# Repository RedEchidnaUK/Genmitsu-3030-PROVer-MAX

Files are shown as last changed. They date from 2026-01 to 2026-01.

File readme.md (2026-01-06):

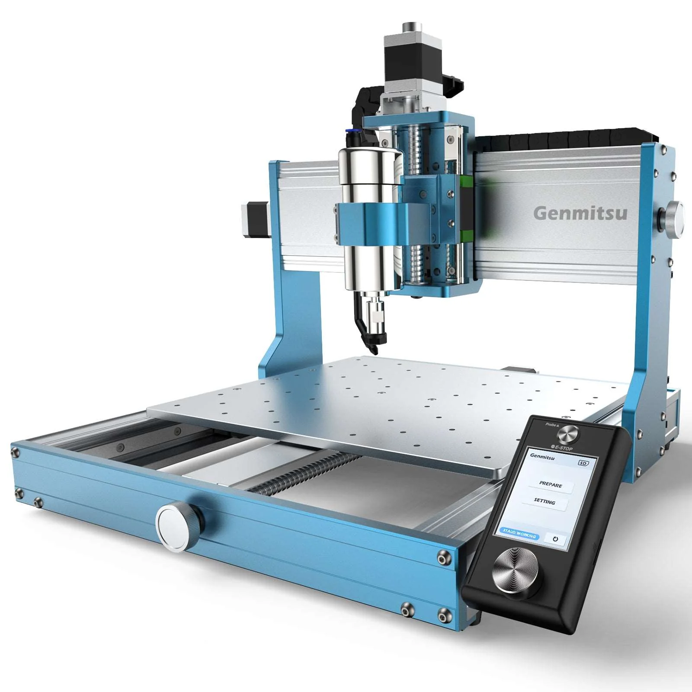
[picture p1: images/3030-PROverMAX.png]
Photo of Genmitsu 3030 PROVer MAX


# Overview
This repository is to document information and modifications on the [Genmitsu 3030 PROVer MAX](https://www.sainsmart.com/products/3030-prover-max) Desktop CNC Router.

Each folder contains information and files about a specific topic.

# Contents
1. [Enclosure](./enclosure/readme.md)
2. [Probes](./probes/readme.md)
3. [E-Stops](./estops/readme.md)
4. [Micro PCB](./microPCB/readme.md) for custom probes and E-Stops

## Notes
* All of this information is provided as is and is not intended as a fully detailed guide. 
* No warranty is provided and you use the information at your own risk. 
* If you break your CNC or your cat/dog goes paws up you can not say you were not warned.

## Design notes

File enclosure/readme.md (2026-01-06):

# Enclosure
This section contains information on building an enclosure for the CNC.

It is designed for the standard range of travel motions and with the standard stepper motors in place. If you modify any of these, you may have to make changes to the size of the enclosure. Although not tested, it has been designed to allow for the use of a 1.5Kw 65mm spindle.

The offline controller should be placed outside the enclosure and may be attached with M4 T-Nuts. The cables should be just long enough, but if they are not extensions may be found on AliExpress (search for JST PH and JST PHB extensions)

It is recommended to read through all of this information prior to commencing any work.
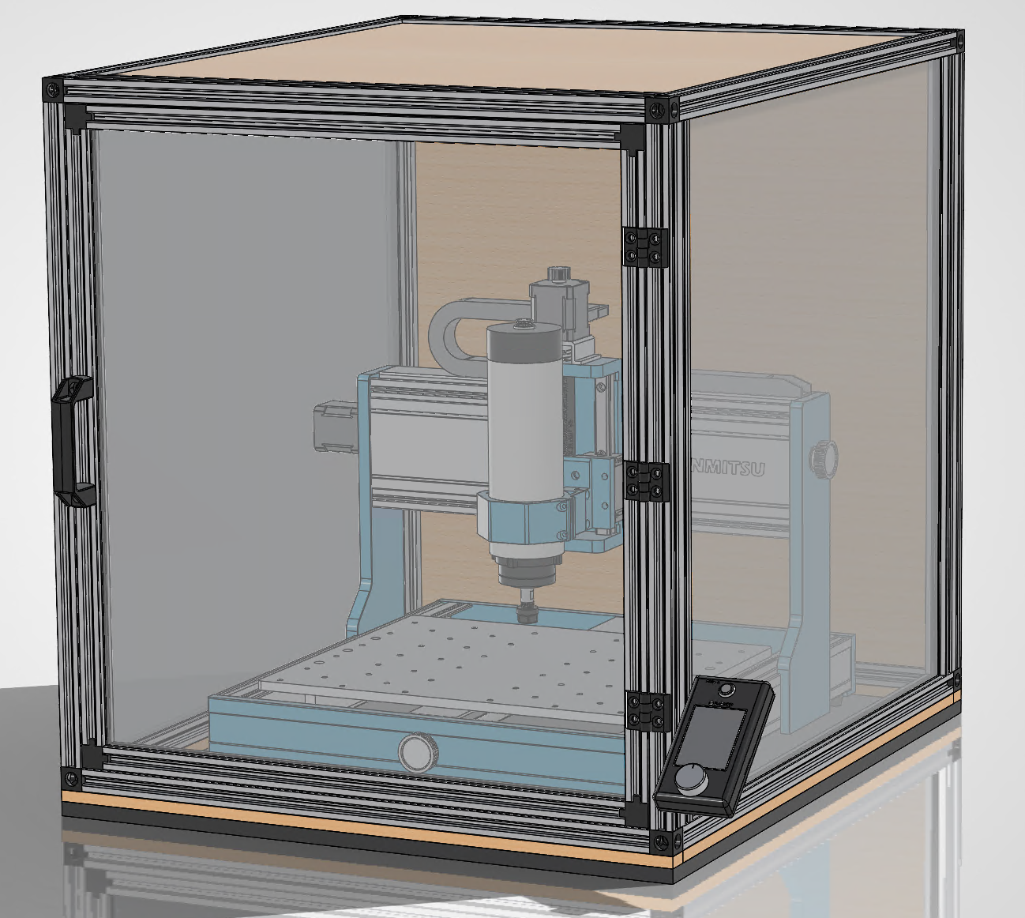
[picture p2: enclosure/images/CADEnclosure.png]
Enclosure CAD model

<sup>1</sup> Genmitsu CAD model shown is from [Printables](https://www.printables.com/model/1285038-genmitsu-3030-prover-max)

## Bill of Materials (BOM)

### Purchased Parts
| Item | Quantity | Supplier (UK) | Notes |
| - | - | - | - |
| **2020** Aluminium Extrusion (**478mm**) | 2 | [Ooznest](https://ooznest.co.uk/) | Tapped both ends (Door top/bottom)|
| **2020** Aluminium Extrusion (**518mm**) | 2 | [Ooznest](https://ooznest.co.uk/) | Tapped both ends  (Door sides) |
| **2020** Aluminium Extrusion (**520mm**) | 2 | [Ooznest](https://ooznest.co.uk/) | Tapped both ends (Front/Rear base) |
| **2020** Aluminium Extrusion (**620mm**) | 4 | [Ooznest](https://ooznest.co.uk/) | Tapped both ends (Sides) |
| **2040** Aluminium Extrusion (**520mm**) | 2 | [Ooznest](https://ooznest.co.uk/) | Tapped both ends (Front/Rear top) |
| **2040** Aluminium Extrusion (**560mm**) | 4 | [Ooznest](https://ooznest.co.uk/) | Tapped both ends (Front/Rear sides) |
| 20 Series T/V-Slot Panel Sealing Strip | 12m | [Ooznest](https://ooznest.co.uk/) | Lubrication was required even with 3mm panel. Strips are a hard plastic and not rubber. Alternatives may be better |
| 2020 Door Handle | 1 | [Ooznest](https://ooznest.co.uk/) | |
| 2020 Hinge | 3 | [Ooznest](https://ooznest.co.uk/) | |
| M4 T-Nut | 16 | [Ooznest](https://ooznest.co.uk/) | |
| M5 T-Nut | 14 | [Ooznest](https://ooznest.co.uk/) | |
| M4x12 CSK Screw | 8 | [Ooznest](https://ooznest.co.uk/) | Length depends on the stripwood thickness|
| M5x8 Low Profile Screw | 12 | [Ooznest](https://ooznest.co.uk/) | Door Hinges |
| M5x14 CSK Screw | 8 | [Ooznest](https://ooznest.co.uk/) | Only required if using the 3D printed corners. |
| 2020 Corner Cube | 12/8 | [Amazon](https://www.amazon.co.uk/dp/B08Z3GRQCW/?coliid=I1LXS3MRZ1L2MV&colid=A492FOWYBVRB&th=1) | UK use 5mm screws, other countries use 6mm. This kit contained both. Only 8 required if using the 3D printed corners. |
| Polycarbonate Sheet (**530mm x 570mm**) | 2 | [SimplyPlastics](https://www.simplyplastics.com/catalog/sheet/polycarbonate-sheet/clear-polycarbonate-sheet/c-24/c-90/p-256) | Sides |
| Polycarbonate Sheet (**488mm x 528mm**) | 1 | [SimplyPlastics](https://www.simplyplastics.com/catalog/sheet/polycarbonate-sheet/clear-polycarbonate-sheet/c-24/c-90/p-256) | Door |
| Plywood/MDF Top (**530mm x 590mm**)| 1 | Local builders merchant, Wickes, B&Q etc. | See [Assembly Notes](#wood-panels) |
| Plywood/MDF Rear (**530mm x 570mm**)| 1 | Local builders merchant, Wickes, B&Q etc. | See [Assembly Notes](#wood-panels) |
| 20mm wide stripwood Front/Rear **560mm** | 2 | Local builders merchant, Wickes, B&Q etc. | Can use offcuts from the wood panels |
| 20mm wide stripwood Side **620mm** | 2 | Local builders merchant, Wickes, B&Q etc. | Can use offcuts from the side panels |
| Anti-Vibration Matting) | 1 | [Screwfix](https://www.screwfix.com/p/essentials-shock-absorbing-floor-mat-black-620mm-x-620mm-x-12mm/967KN) | Slightly undersized in the length, but the width offcuts may be attached with polyurethane adhesive.|
| 20mm x 4mm x 2mm thick N42 Neodymium Magnet - 1.9kg Pull | 8 | [First4Magnets](https://www.first4magnets.com/product/20-x-4-x-2mm-thick-n42-neodymium-magnet-19kg-pull-19305?variant=1151) | |
| 6mm x 6mm Flexible LED Strip | 3m | [AliExpress](https://www.aliexpress.com/item/1005007424507477.html) | |

### Optional 3D Printed Parts
| Item | Quantity | Link | Notes |
| - | - | - | - |
| 2020 2-Way Corner Cube | 4 | [3MF file](./3DPrintFiles/2020CornerCube2Way.3mf) | A normal cube may be used but you will have to notch the panel corners. |
| Magnet Holder | 4 | [3MF file](./3DPrintFiles/MagnetHolder.3mf) | The magnets could be directly glued in place. |

# Assembly Notes

## Wood Panels
A 'half sheet' (606 x 1220mm/2' x 4') cut carefully will be enough for both the rear and top panel as well as the base strips.

Depending on the thickness of the wood purchased  you may have to rabbet the edge to fit in the Aluminium extrusion or Panel Sealing Strip.

The corners on the rear panel will also have to be removed to fit around the corner cube

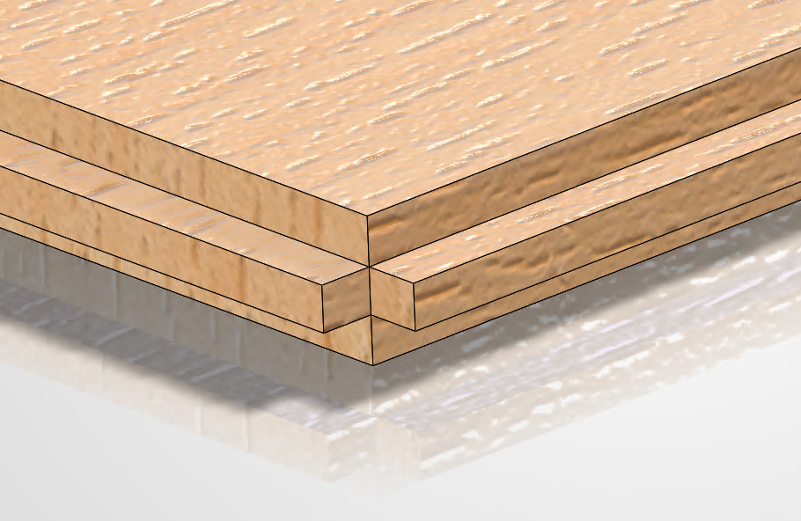
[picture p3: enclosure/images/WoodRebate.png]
Wood Rabbet


## Base Strips
Strips of wood are fitted around the base and are held in place by M4 CSK screws and T-Nuts. These are designed to allow notches to be easily cut for any wires coming in/out of the enclosure.

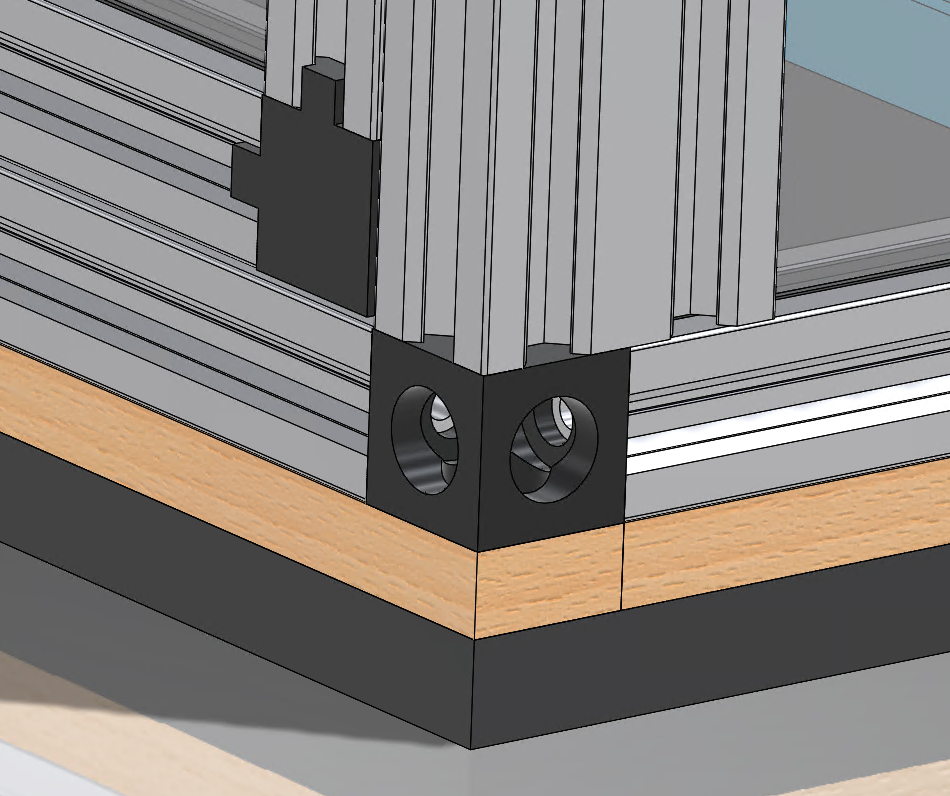
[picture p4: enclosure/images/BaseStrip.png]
Wood Base Strip


## Door
### Door Panel Corners
If you are not using the 3D printed corner cubes you will need to remove the corners of the door panel in the same way as the wood panels to fit around the corner cubes.

The [3D printed corner cubes](./3DPrintFiles/2020CornerCube2Way.3mf) have notches in them to avoid this modification

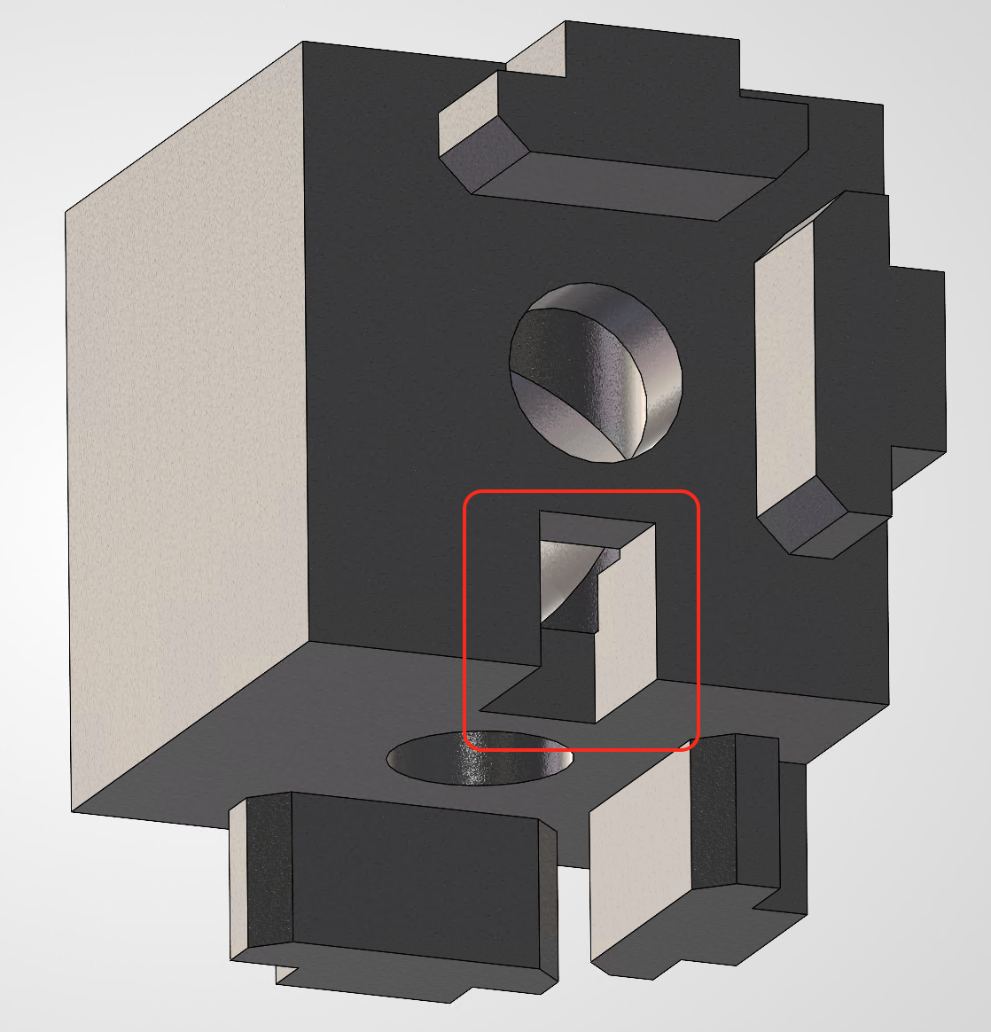
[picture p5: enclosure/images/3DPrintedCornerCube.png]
3D Printed Corner Cube


### Door Magnets
Magnets may be used to create a surprisingly good invisible door catch. Make sure to put the magnets in the correct orientation and align them opposite each other so they are attracted to each other when the door is closed. 

> [!TIP]
> Each [3D printed holder](./3DPrintFiles/MagnetHolder.3mf) is designed to have two magnets fitted, but the number may be adjusted to change the strength of the catch.

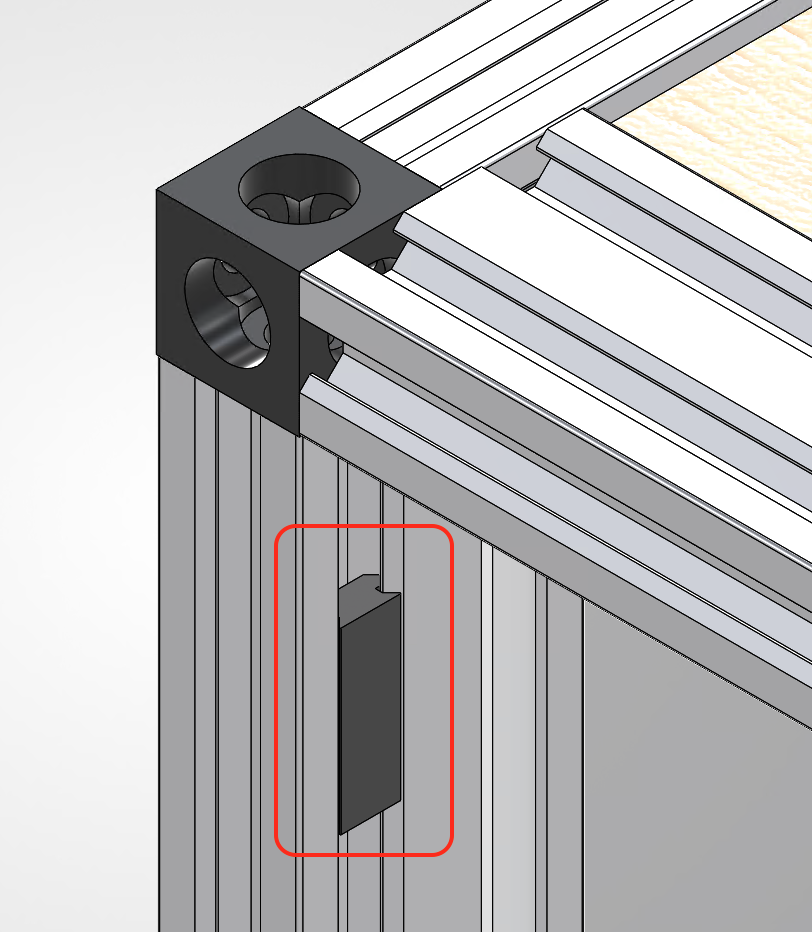
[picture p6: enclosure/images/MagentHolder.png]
Door Magnets


If you are concerned with the door being opened during operation and someone being injured, fit a lockable catch or a magnetic switch to trigger the [E-Stop](../estops/readme.md).

## LED Lighting
6mm x 6mm narrow flexible LED strips fit perfectly in the 6mm wide and deep channels of the 2040 extrusion at the front and rear of the enclosure.
Simply push fit them in one side, over the top and down the other side. 

Modify the extrusions as required to allow the wires to exit the enclosure.

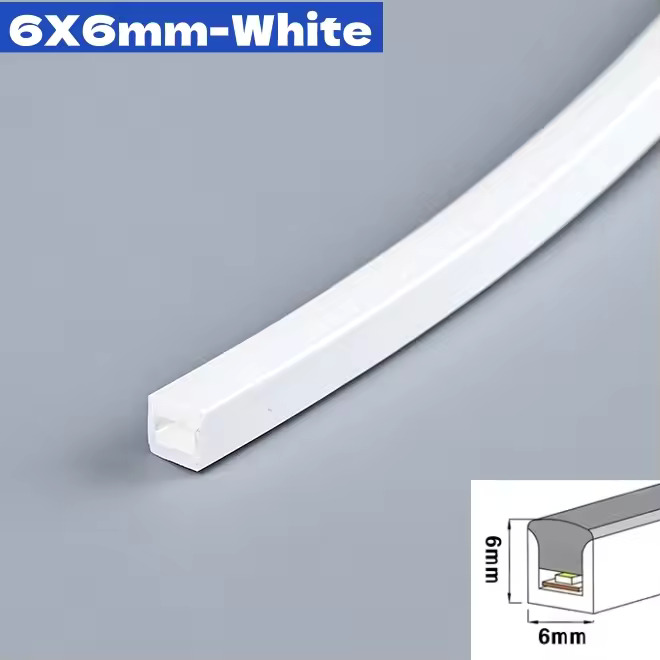
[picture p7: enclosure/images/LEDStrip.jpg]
6mm x 6mm Flexible LED Strip


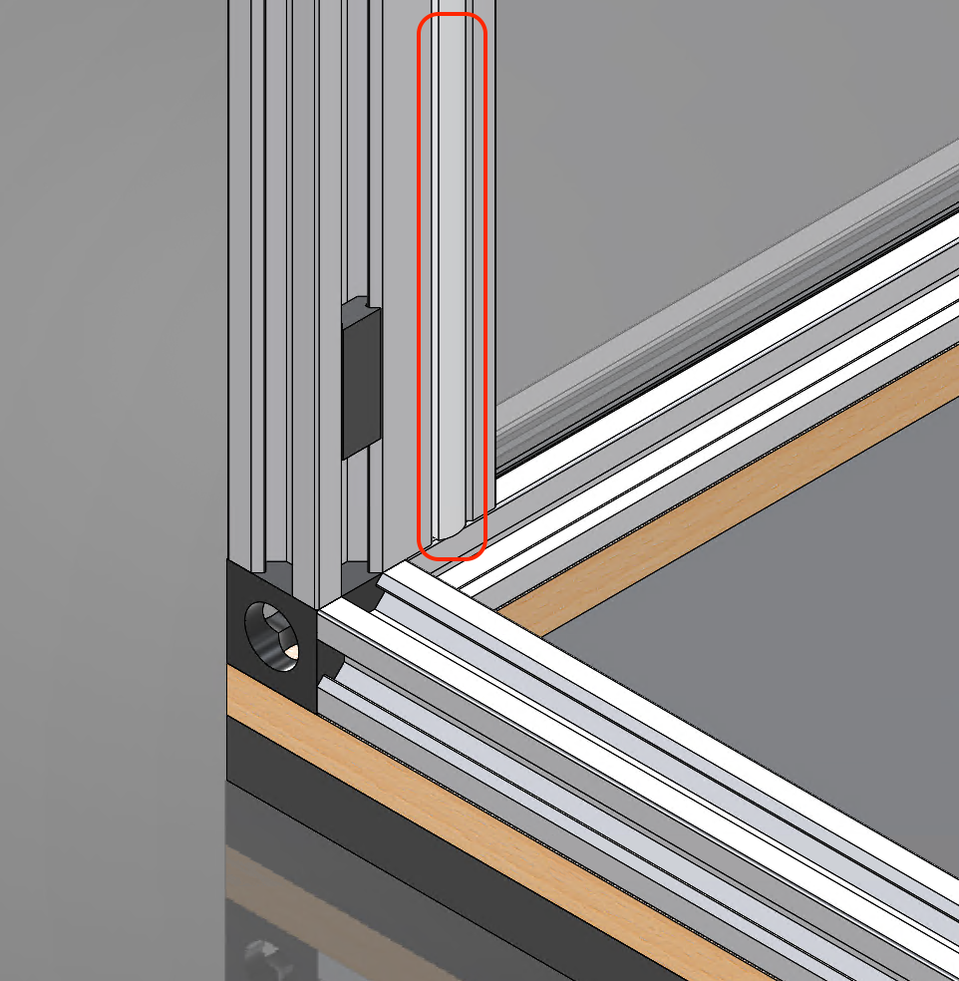
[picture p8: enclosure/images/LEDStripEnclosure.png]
Flexible LED Strip in the Enclosure


> [!TIP]
> When wiring the LED strip, connect to the wiring point just beyond the first section of LEDs. This will allow the wires to bend more easily without breaking the solder joint. Silicone sealant may also be used to reenforce the joint.

> [!TIP]
> The LED strip can be run at less than 12v to extend the life of the LEDs while still providing enough illumination.

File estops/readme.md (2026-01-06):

# E-Stops
This section contains information on stopping the machine in an emergency.

## Normally Closed or Normally Open?
In their most basic form, E-Stops are just switches, but switches can come in two forms, Normally Closed (NC) and Normally Open (NO). It's important to understand the difference between these when purchasing emergency stop switches as the wrong type will not directly work with the CNC controller. 

### Normally Closed (NC)
A Normally Closed (NC) switch maintains a closed circuit by default, allowing current to flow through it when it is in its normal, inactivated state. When it is pressed the switch opens and current can no longer flow. 

Generally, NC switches should be used for safety mechanisms, such as an *Emergency Stop*, as a damaged wire will inherently trigger the stop

### Normally Open (NO)
A Normally Open (NO) switch maintains an open circuit by default, preventing current flow through it when it is in its normal, inactivated state. When it is pressed the switch closes and current can flow. 

## Emergency Stop (E-Stop) - Overview
In the authors opinion, the emergency stop on the Genmitsu<sup>*</sup> has a few design flaws,

1. It relies on a NO switch
2. It is not independent of the controller
3. The E-Stop button is small and may not be easy to reach in a panic

The first becomes an issue if there is any fault in the wiring/switch as the fault itself will not trigger a fault condition. Which leads to only finding out about the fault when the E-Stop button is pressed and nothing happens...

The second is an issue if the controller itself can't respond to the E-Stop button press. Which could happen if the controller has crashed.

The first two issues may mitigate to some extent with external electronics and the third can be mitigated by either replacing the current E-Stop button or wiring in an additional button in parallel.

<sup>*</sup> To be fair to SainSmart, almost all of these desktop CNCs that are produced down to a low price have the same flaws.

### Converting from a NO to NC E-Stop
As shown in the [Probe](../probes/readme.md#tool-setter-and-a-3d-touch-probe) section, it is possible to convert a NO to a NC circuit. This solution is not 100% perfect, as a fault between the invertor circuit and the controller would still result in an unknown fault condition. However, it could help lower this risk and it does allow you to connect extra NC switches in the E-Stop circuit. Such as the one on a tool setter or an enclosure door switch.

Below is a simple circuit that may be used to convert a NO connection to a NC connection and has support for multiple inputs. If multiple inputs are not required, simply remove them or use a jumper to permanently short them.

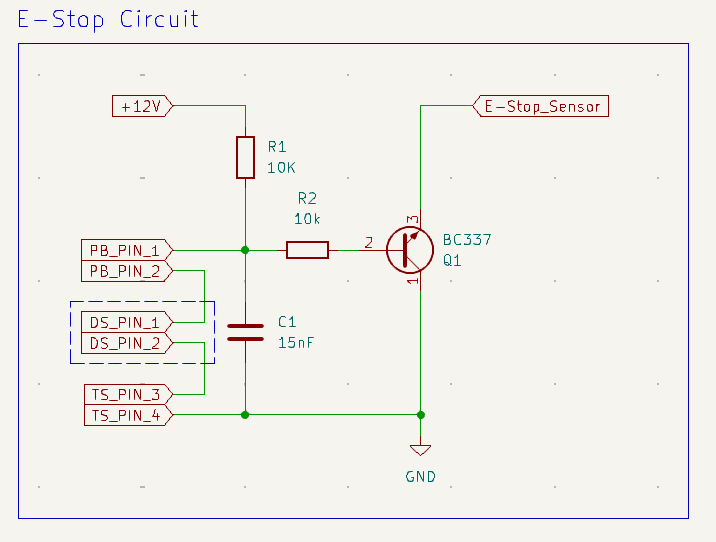
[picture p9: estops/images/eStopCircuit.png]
E-Stop Circuit


To connect the circuit to the Genmitsu you will have to open up the offline controller, or the main controller, and connect to the E-Stop pins. Both use a standard JST PH connector and if soldering directly to the PCB it not an option splitter cables may be found on AliExpress/eBay

### Safety Relays
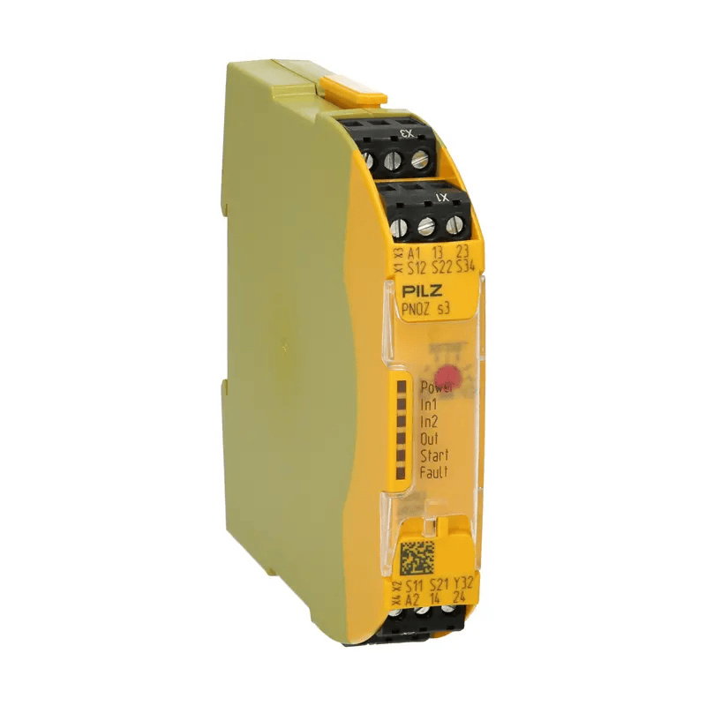
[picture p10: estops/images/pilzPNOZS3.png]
Pilz Safety Relay

Safety relays are a large topic and there are many different types for many different situations and many ways of wiring them. Therefore, this guide is only intended to introduce them and their benefits. 

A safety relay is a special type of relay that contains electronics that monitor inputs to ensure they are working as expected and only allows equipment to be started when it is safe to do so. Should an E-Stop be pressed, or depending on the relay, a fault detected with the E-Stop or relay, then power will be automatically cut off to the externally controlled equipment completely independently of any other electronics.

New safety relays can be very expensive $100+, but they can often be picked up second-hand online for a fraction of the price.

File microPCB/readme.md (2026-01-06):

# Example Probe and E-Stop Circuit/PCB
By combining the two circuits discussed in the [probe](../probes/readme.md) and [e-stop](../estops/readme.md) information, it is possible to connect a NC tool setter (with end stop protection), a NO 3D Touch Probe and two external E-Stop switches to the Genmitsu controller via a Stripboard PCB

> [!CAUTION]
> This PCB has NOT been tested. Use at your own risk!

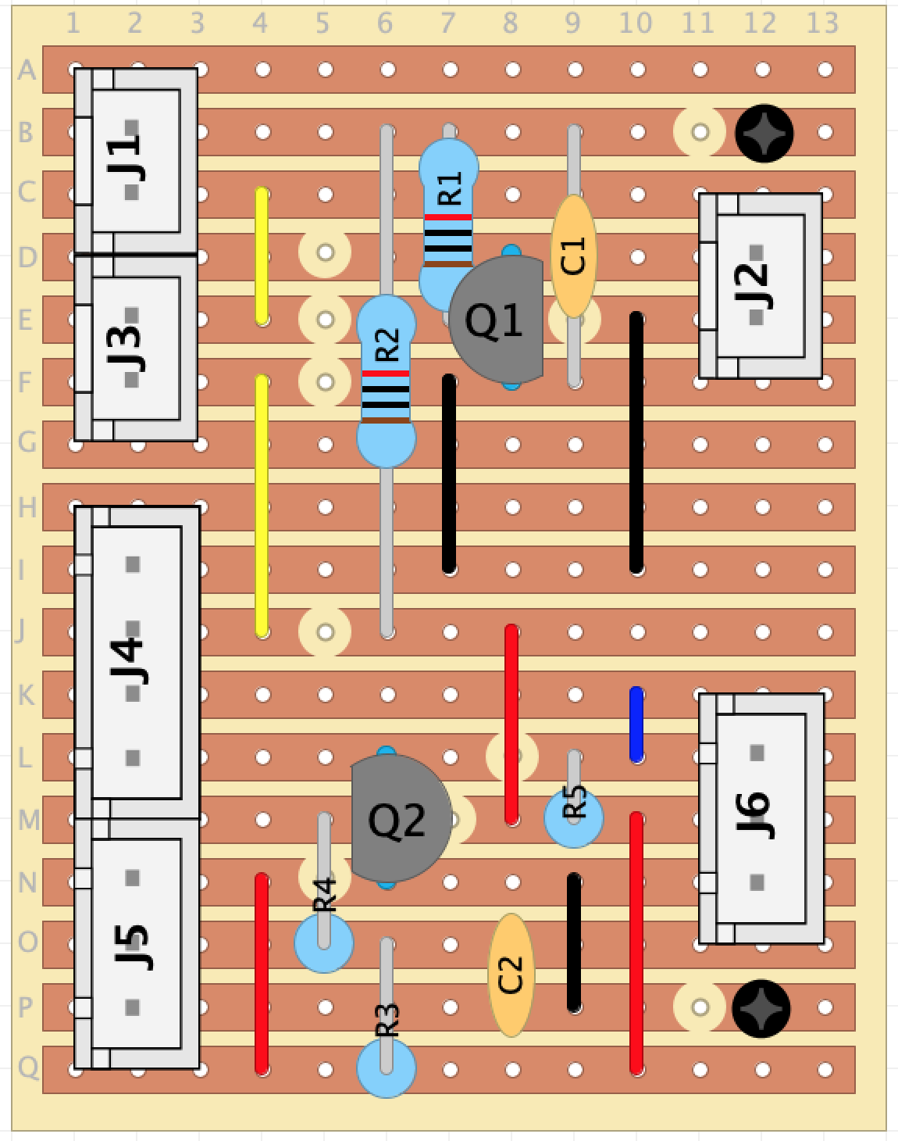
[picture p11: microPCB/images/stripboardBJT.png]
Probe and E-Stop Stripboard PCB

Designed using [DIYLC](https://github.com/bancika/diy-layout-creator/releases) and the layout may be found [here](./circuit/stripboardBJT.diy) 

A PDF of the full circuit may be found [here](./circuit/GenmitsuMicroPCBschematic.pdf) 

The above PCB uses JST PH connectors, but these could be swapped out for small terminal connectors if you do not have the tools to crimp the terminals.

> [!WARNING]
> Make sure to mirror the stripboard when drilling the holes to cut the traces. A mirrored version may be found [here](./images/stripboardBJTMirrored.png)

**Bill of Materials**
| Item |  Description | Value |  Quantity  |
| - | - | - | - |
| Stripboard | - | 17V x 13H | |
| R1 -> R5 | Resistor | 10K | 5 |
| Q1, Q2 | NPN Transistor | BC337<sup>1</sup> | 1 |
| J1 -> J3 | JST PH Header  | 2 Pin | 4 |
| J5, J6 | JST PH Header  | 3 Pin | 2 |
| J4 | JST PH Header  | 4 Pin | 1 | 

<sup>1</sup> Other BJT or MOSFET may also be suitable, e.g. 2N2222, BS170

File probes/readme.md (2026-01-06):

# Probes
This section contains information on Probes for setting the length of tools and for acurately identifying work coordinates.

## Normally Closed or Normally Open?
Probes are essentially just switches, but switches can come in two forms, Normally Closed (NC) and Normally Open (NO). It's important to understand the difference between these when purchasing probes as the wrong type will not directly work with the CNC controller. 

### Normally Closed (NC)
A Normally Closed (NC) switch maintains a closed circuit by default, allowing current to flow through it when it is in its normal, inactivated state. When it is pressed the switch opens and current can no longer flow. 

Generally, NC switches should be used for safety mechanisms, such as an *Emergency Stop*, as a damaged wire will inherently trigger the stop (more information may be found in the [Emergency Stop](../estops/readme.md) section)

### Normally Open (NO)
A Normally Open (NO) switch maintains an open circuit by default, preventing current flow through it when it is in its normal, inactivated state. When it is pressed the switch closes and current can flow. 

## Tool Setter
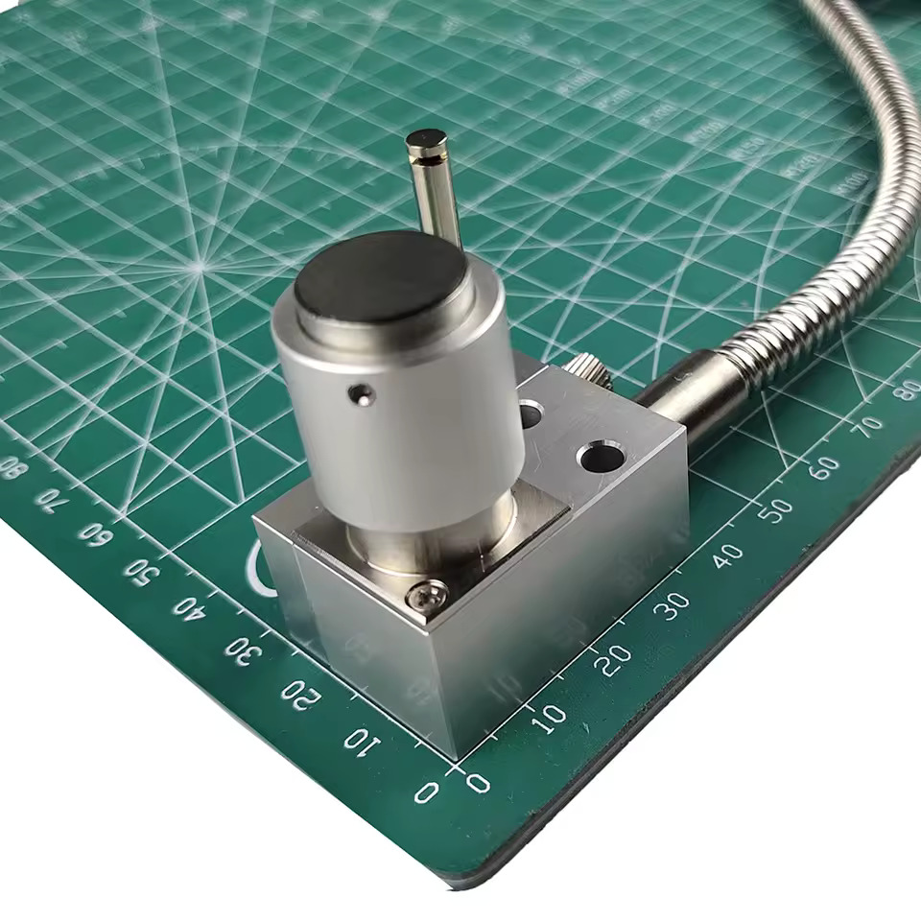
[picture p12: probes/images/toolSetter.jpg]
Generic Tool Setter


Generic NC tool setters that are used to determine the length of a tool in the spindle may be found on AliExpress for around $35. These often also have travel over limit protection that should be wired to an E-Stop to help prevent damage to a tool that is not detected for some reason.

If you connect this directly to the probe input on the Genmitsu you will have to reverse the input in the software using the `$6=1` command. This is because the standard probe expects a (NO) connection.

A typical pinout is shown below, but pinouts vary between manufacturers so always check them,

| Purpose | Wire |
| - | - |
| Probe Signal | Brown, Black |
| Over Limit Protection | Green, White |

## 3D Touch Probe
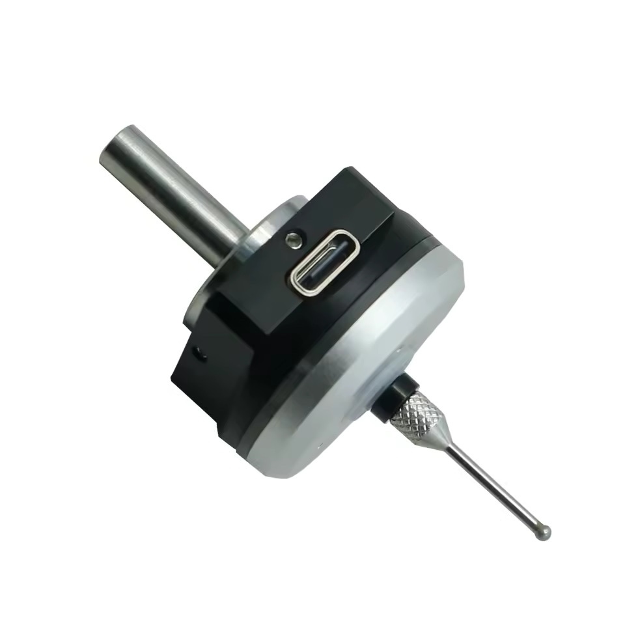
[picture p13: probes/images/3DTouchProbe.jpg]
Generic 3D Touch Probe


Generic NO 3D Touch Probes may be found on AliExpress for around $45. These are used to determine the work coordinates of the part to be machined.

NC versions are also available, but seem to be a lot harder to find and often cost more at around $75

If you connect this directly to the probe input on the Genmitsu it should work out of the box. 

## Tool Setter and a 3D Touch Probe
If you want to use both a Tool Setter and a 3D Touch Probe and have both wired at the same time, you may want to buy **NC** versions of both. Then you can just wire them in series, and everything will work as expected. 

However, this method does have the disadvantage of having to have the 3D Touch Probe permanently connected.

Things become a bit more complicated if you buy a NC Tool Setter and a **NO** 3D Touch Probe, but it is possible to get them to work together with a small circuit. 

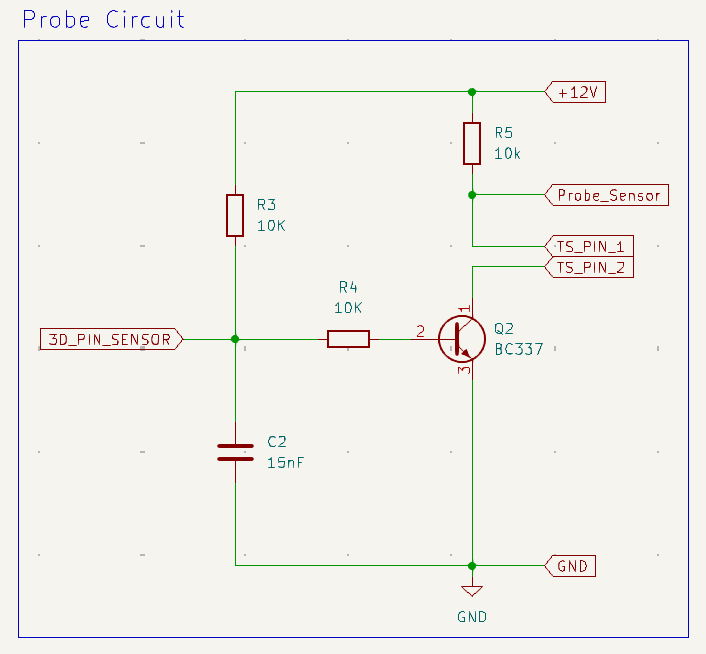
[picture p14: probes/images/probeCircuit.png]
Probe Sensor Circuit


This circuit works by inverting the NO 3D touch probe signal via an NPM transistor, effectively converting it to a NC signal. 

The *+12V*, *GND*, and *Probe_Sensor* are provided by the Genmitsu controller via the **2.5mm** jack. Alway check pinouts, but usually they are as follows,

| Pin | Wire | Function |
| - | - | - |
| Tip | White | Sensor Signal |
| Ring | Red | +12V Supply |
| Sleeve | Black | Ground |

Image of 2.5mm Jack Plug identifying pins

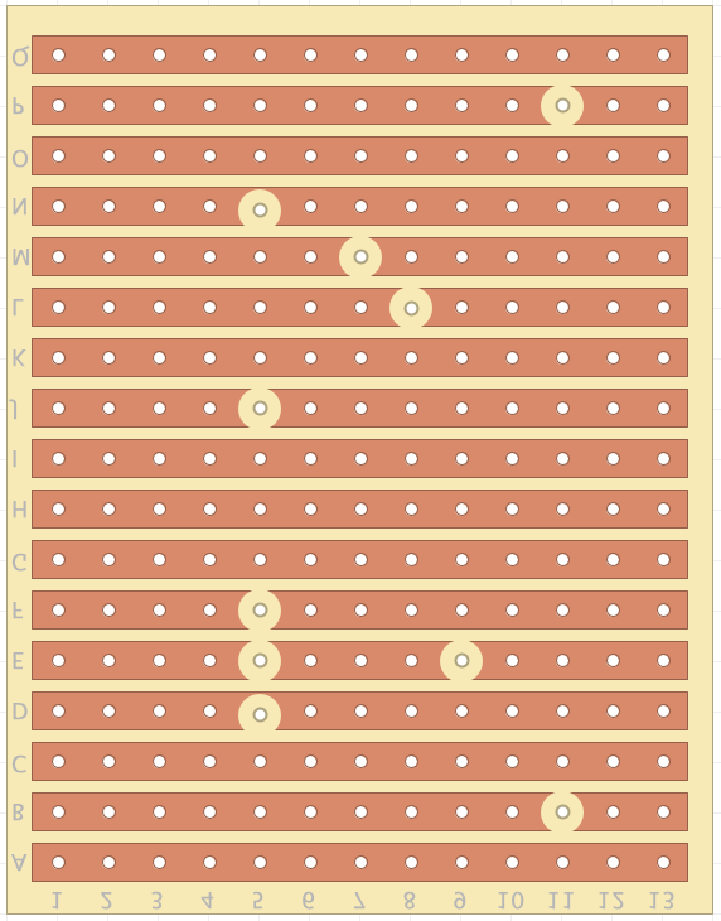
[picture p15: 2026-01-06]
microPCB/images/stripboardBJTMirrored.png

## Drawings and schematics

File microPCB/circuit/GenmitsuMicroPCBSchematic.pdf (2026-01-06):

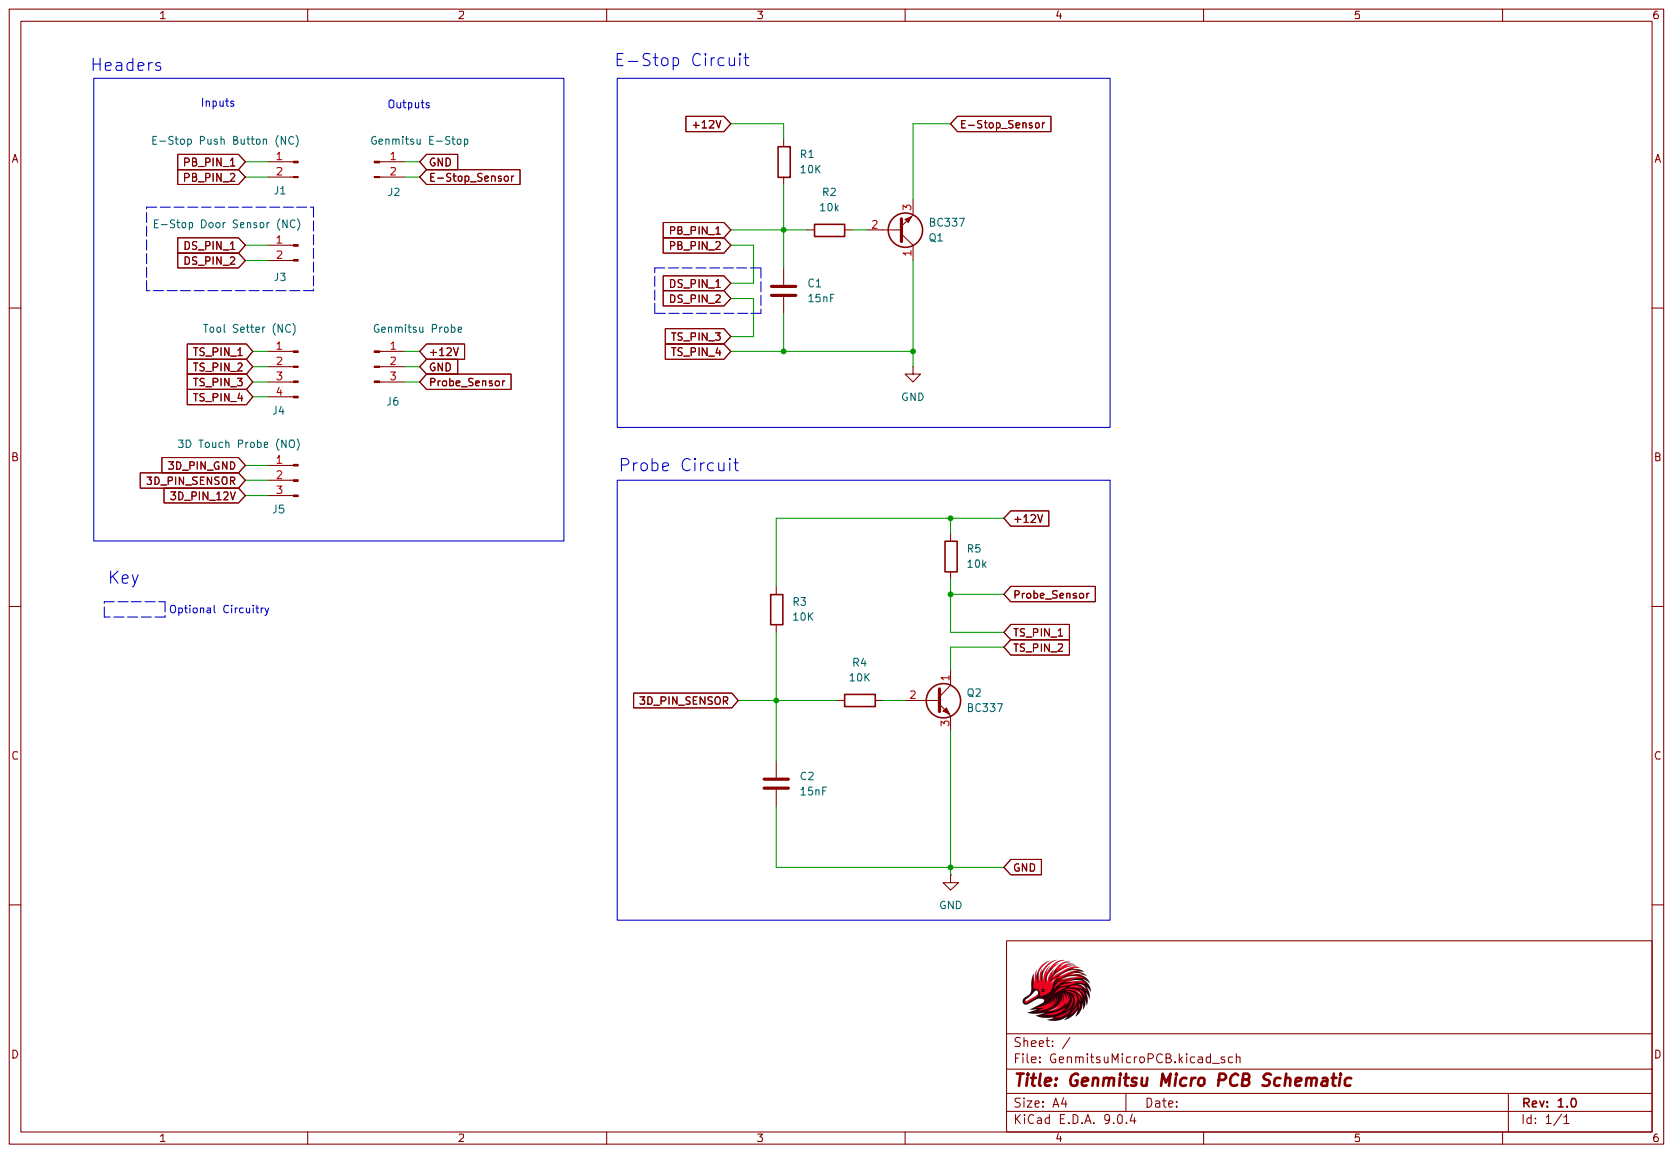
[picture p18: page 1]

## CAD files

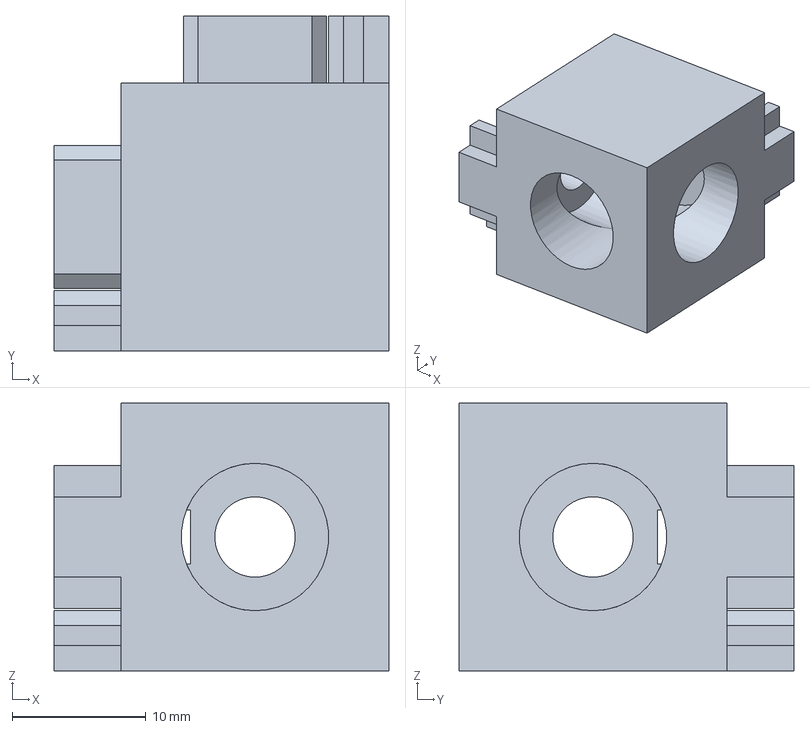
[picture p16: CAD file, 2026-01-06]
enclosure/3DPrintFiles/2020CornerCube2Way.3mf
25.0 x 25.0 x 20.0 mm

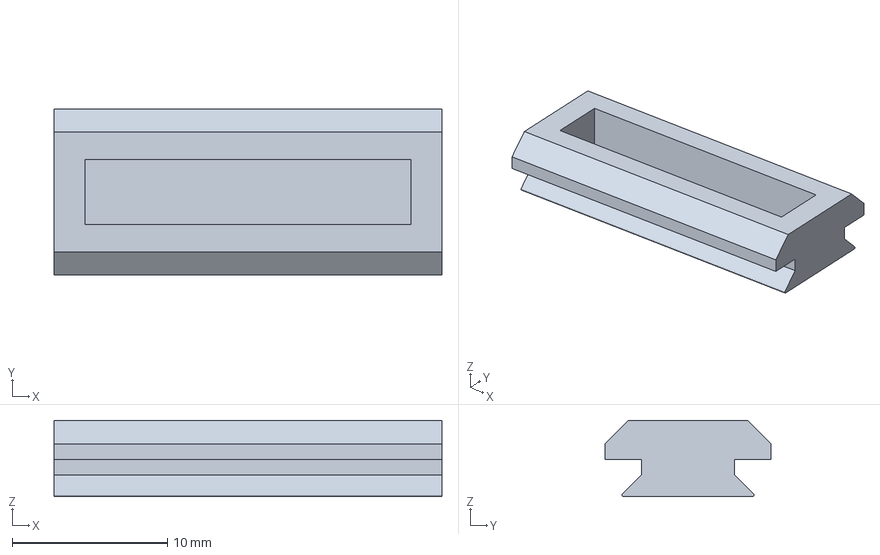
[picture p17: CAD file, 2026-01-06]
enclosure/3DPrintFiles/MagnetHolder.3mf
25.0 x 10.7 x 4.90 mm
